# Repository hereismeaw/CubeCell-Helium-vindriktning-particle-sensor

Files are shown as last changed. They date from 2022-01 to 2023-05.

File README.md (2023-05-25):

# Helium LoRaWAN connectivity for the Ikea VINDRIKTNING

This repository contains an Heltec CubeCell firmware, which adds Helium LoRaWAN connectivity to the Ikea VINDRIKTNING PM2.5 air quality sensor.
The modification doesn't interfere with normal operation of the IKEA device in any way.
The CubeCell just adds another data sink beside the colored LEDs.

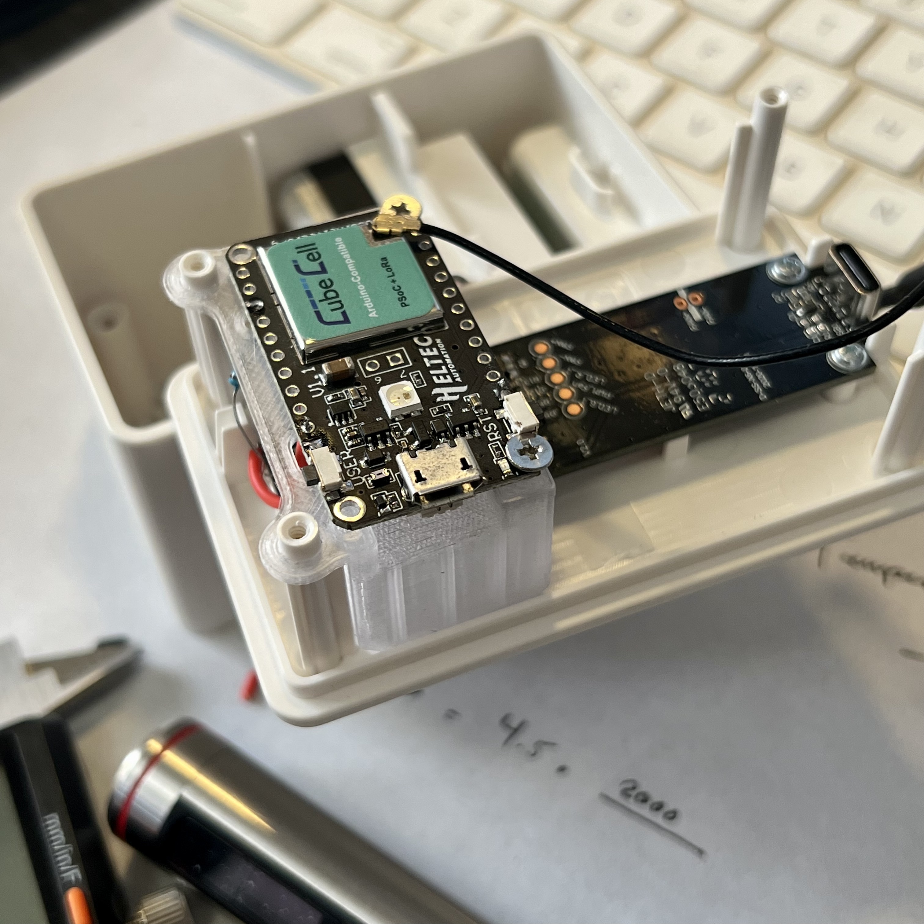
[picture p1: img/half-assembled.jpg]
half_assembled


The CubeCell seems to be 5V-tolerant, but just in case you can wire in the data line with a voltage divider.
## Prerequisites
To extend your air quality sensor, you will need

- A LoRaWAN-enabled dev board, in this case the [Heltec CubeCell HTCC-AB01](https://heltec.org/project/htcc-ab01/) ([US Domestic](https://shop.parleylabs.com/collections/iot-developers-products/products/cubecell-dev-board-by-heltec-htcc-ab01))
- Some short dupont cables
- A soldering iron
- A long PH0 Screwdriver (e.g. Wera 118022)

Fortunately, there is a lot of unused space in the enclosure, which fits the HTCC-AB01 well.
Also, everything we need is accessible via easy to solder testpoints.
## Hardware
To install, just unscrew the four visible screws in the back of the enclosure.

There are also three screws holding the IKEA PCB in place. These aren't necessary to remove since you can solder in-place, however personally, I'd recommend taking the board out of there since it will be easier to solder without fear of accidentally melting some plastic.

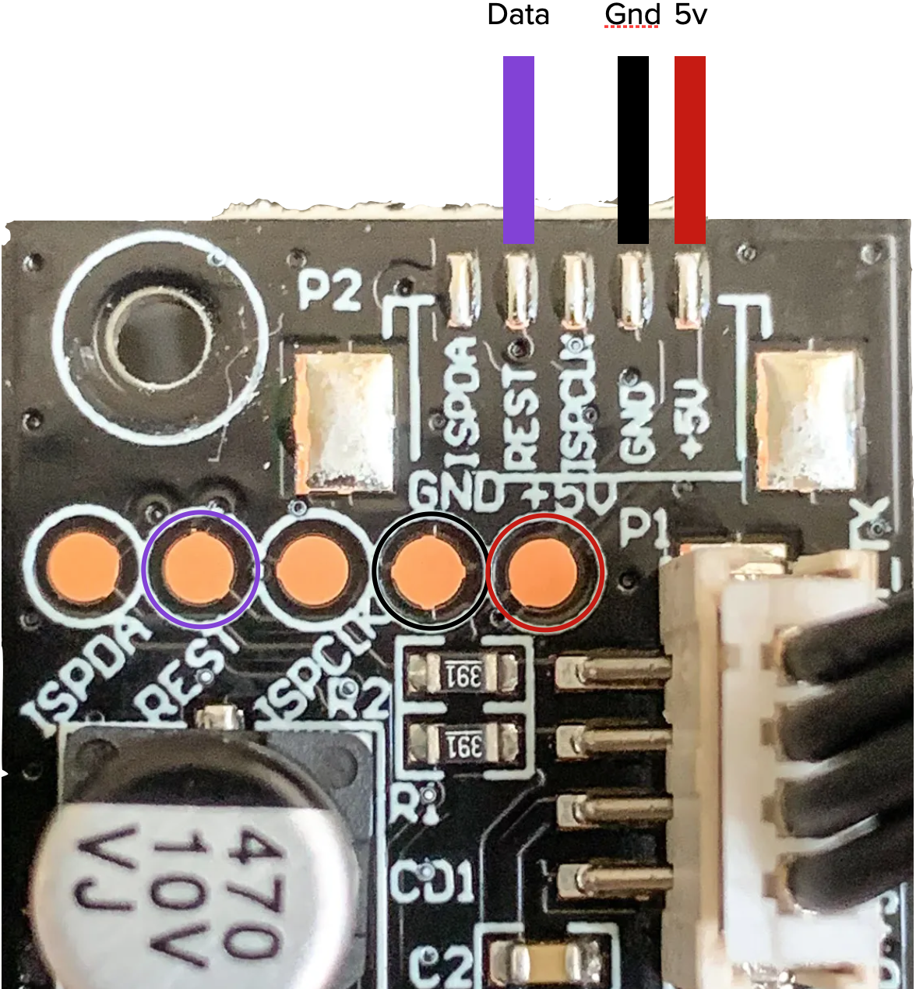
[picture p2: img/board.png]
board


As you can see in this image, you'll need to solder wires to GND, 5V and the Testpoint that is connected to TX of the Particle Sensor.

Then just connect these Wires to GND, VIN (5V) and Pin 2 on the CubeCell.
<table>
  <tr>
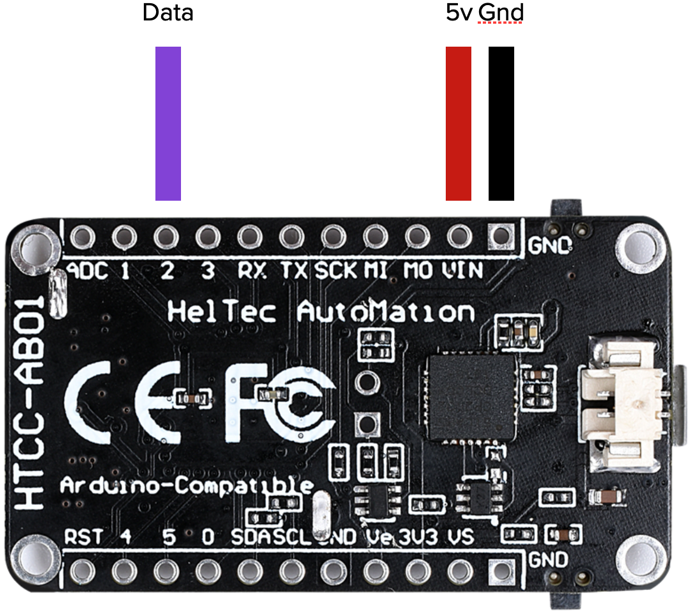
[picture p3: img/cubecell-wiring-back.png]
    <td valign="bottom"></td>
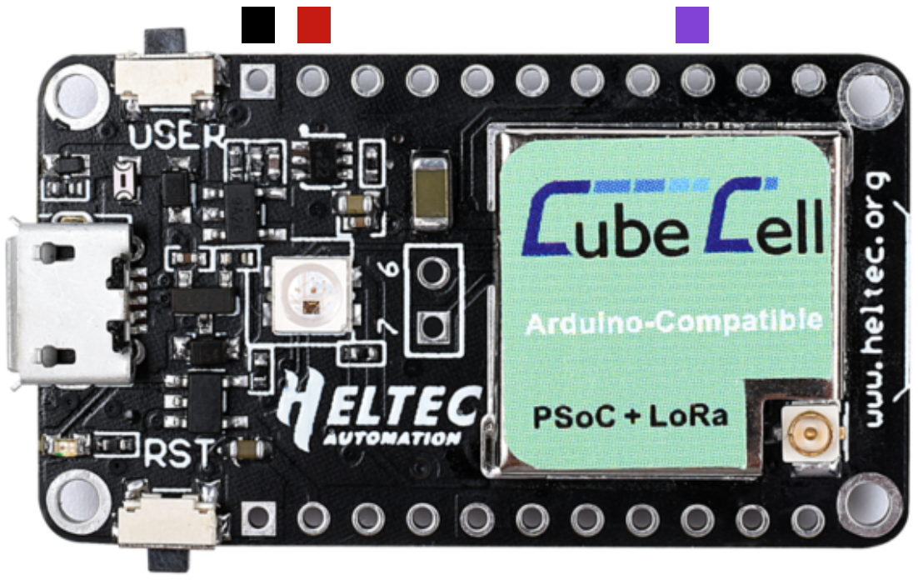
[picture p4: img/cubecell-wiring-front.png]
    <td valign="bottom"></td>
  </tr>
</table>

[Optional] If you choose to include a voltage divider, you can wire it in as follows:
voltage divider

Done.
## Software
The firmware can be built and flashed with [VS Code](https://code.visualstudio.com) using the PlatformIO plugin. PRs welcome for any Arduino IDE support/testing.

You can follow the guide below to set up the PlatformIO environment and CubeCell board:

https://docs.helium.com/use-the-network/devices/development/heltec/cubecell-dev-board/platformio/

LoRaWAN network keys will need to be added in the code. All keys are MSB.
After keys are added; just build, flash, and you're done.

## Downlinks
### Update Interval
By default, the sensor will update on a 1 minute interval. LoRaWAN update interval is configurable via LoRaWAN downlink. Set the interval in hours, minutes, or both. Values are submitted in two separate buckets, `[hours]` and `[minutes]`. Values up to 255 are supported in each bucket. Use a tool like https://v2.cryptii.com/decimal/base64 to convert the two values into base64 before submitting them as a downlink in Helium Console. e.g.
```
"00 15" converts to "AA8=", representing 0 hrs, 15 min
```
Values are added, so `01 15` is equivalent to `00 75`. Further, `02 00` = `00 120` etc.

## Misc
The VINDRIKTNING consists of a custom(?) Cubic PM1006-like Sensor + another uC that does all that LED stuff, which talk via UART. Therefore, to add LoRaWAN connectivity, we just need to also listen to the TX of the Sensor and decode those messages.
The transitions from Green to Yellow and Yellow to Red in the Ikea firmware are at around 30μg/m³ and 100μg/m³. There is a great analysis of the sensor's capabilities [here](https://www.airgradient.com/resources/ikea-vindriktning-accuracy/).
## References and sources
- [Source Repo](https://github.com/Hypfer/esp8266-vindriktning-particle-sensor)
- [Sensor analysis](https://www.airgradient.com/resources/ikea-vindriktning-accuracy/)
- [@haxfleisch](https://twitter.com/haxfleisch) for their teardown of the device.
- [Gabriel Valky](https://github.com/gabonator) for the incredibly useful [LA104 custom firmware + tools](https://github.com/gabonator/LA104)

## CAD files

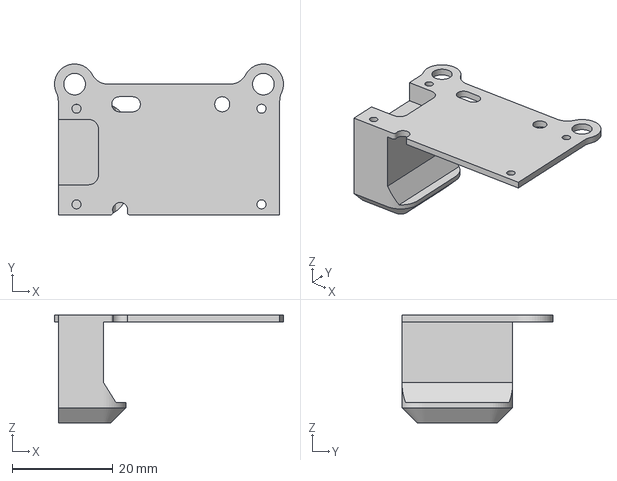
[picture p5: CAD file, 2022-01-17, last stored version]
3d_print/Vindriktning-Cubecell-Mount.3mf
45.5 x 30.0 x 21.4 mm

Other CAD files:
3d_print/Vindriktning-Cubecell-Mount.f3d
3d_print/Vindriktning-Cubecell-Mount.stl

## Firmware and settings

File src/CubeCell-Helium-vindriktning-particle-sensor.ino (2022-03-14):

#include "LoRaWan_APP.h"
#include "Arduino.h"
#include "SerialCom.h"
#include "types.h"

particleSensorState_t state;

/* OTAA para*/
/* All keys MSB */
uint8_t devEui[] = { 0x00, 0x00, 0x00, 0x00, 0x00, 0x00, 0x00, 0x00 };
uint8_t appEui[] = { 0x00, 0x00, 0x00, 0x00, 0x00, 0x00, 0x00, 0x00 };
uint8_t appKey[] = { 0x00, 0x00, 0x00, 0x00, 0x00, 0x00, 0x00, 0x00, 0x00, 0x00, 0x00, 0x00, 0x00, 0x00, 0x00, 0x00 };

/* ABP para*/
uint8_t nwkSKey[] = { 0x15, 0xb1, 0xd0, 0xef, 0xa4, 0x63, 0xdf, 0xbe, 0x3d, 0x11, 0x18, 0x1e, 0x1e, 0xc7, 0xda,0x85 };
uint8_t appSKey[] = { 0xd7, 0x2c, 0x78, 0x75, 0x8c, 0xdc, 0xca, 0xbf, 0x55, 0xee, 0x4a, 0x77, 0x8d, 0x16, 0xef,0x67 };
uint32_t devAddr =  ( uint32_t )0x007e6ae1;

/*LoraWan channelsmask, default channels 0-7*/ 
// uint16_t userChannelsMask[6]={ 0x00FF,0x0000,0x0000,0x0000,0x0000,0x0000 };
uint16_t userChannelsMask[6] = { 0xFF00,0x0000,0x0000,0x0000,0x0000,0x0000 }; //Helium Channel Mask

/*LoraWan region, select in arduino IDE tools*/
LoRaMacRegion_t loraWanRegion = ACTIVE_REGION;

/*LoraWan Class, Class A and Class C are supported*/
DeviceClass_t  loraWanClass = LORAWAN_CLASS;

/*the application data transmission duty cycle.  value in [ms].*/
uint32_t appTxDutyCycle = 1800000; //30 min default. Configurable using Downlink

/*OTAA or ABP*/
bool overTheAirActivation = LORAWAN_NETMODE;

/*ADR enable*/
bool loraWanAdr = LORAWAN_ADR;

/* set LORAWAN_Net_Reserve ON, the node could save the network info to flash, when node reset not need to join again */
bool keepNet = LORAWAN_NET_RESERVE;

/* Indicates if the node is sending confirmed or unconfirmed messages */
bool isTxConfirmed = LORAWAN_UPLINKMODE;

/* Application port */
uint8_t appPort = 2;
/*!
* Number of trials to transmit the frame, if the LoRaMAC layer did not
* receive an acknowledgment. The MAC performs a datarate adaptation,
* according to the LoRaWAN Specification V1.0.2, chapter 18.4, according
* to the following table:
*
* Transmission nb | Data Rate
* ----------------|-----------
* 1 (first)       | DR
* 2               | DR
* 3               | max(DR-1,0)
* 4               | max(DR-1,0)
* 5               | max(DR-2,0)
* 6               | max(DR-2,0)
* 7               | max(DR-3,0)
* 8               | max(DR-3,0)
*
* Note, that if NbTrials is set to 1 or 2, the MAC will not decrease
* the datarate, in case the LoRaMAC layer did not receive an acknowledgment
*/
uint8_t confirmedNbTrials = 4;

unsigned char *puc;
/* Prepares the payload of the frame */
static void prepareTxFrame( uint8_t port )
{
	/*appData size is LORAWAN_APP_DATA_MAX_SIZE which is defined in "commissioning.h".
	*appDataSize max value is LORAWAN_APP_DATA_MAX_SIZE.
	*if enabled AT, don't modify LORAWAN_APP_DATA_MAX_SIZE, it may cause system hanging or failure.
	*if disabled AT, LORAWAN_APP_DATA_MAX_SIZE can be modified, the max value is reference to lorawan region and SF.
	*for example, if use REGION_CN470, 
	*the max value for different DR can be found in MaxPayloadOfDatarateCN470 refer to DataratesCN470 and BandwidthsCN470 in "RegionCN470.h".
	*/
    appDataSize = 2;

    puc = (unsigned char *)(&state.avgPM25);
    appData[0] = puc[1];
    appData[1] = puc[0];
}

//downlink data handling function
void downLinkDataHandle(McpsIndication_t *mcpsIndication) {
    Serial.printf("+REV DATA:%s,RXSIZE %d,PORT %d\r\n",mcpsIndication->RxSlot?"RXWIN2":"RXWIN1",mcpsIndication->BufferSize,mcpsIndication->Port);
    
    switch (mcpsIndication->Port) {
    case 1:
        /* Set update interval on port 1 */
        Serial.println("Setting new update interval.");
        Serial.print("Hours: ");
        Serial.println(mcpsIndication->Buffer[0]);
        Serial.print("Minutes: ");
        Serial.println(mcpsIndication->Buffer[1]);
        
        // Multiply slot 1 by 1 hr, slot 2 by 1 minute.
        // Values (0-255) submitted in hex. 
        // Use a tool like https://v2.cryptii.com/decimal/base64. 
        // e.g. `0 15` -> `AA8=` Representing 15 minute interval.
        appTxDutyCycle = (3600000 * mcpsIndication->Buffer[0]) + (60000 * mcpsIndication->Buffer[1]);
        break;
    case 2:
        // todo: control LED on port 2
        // todo: party mode???
        break;
    default:
        break;
    }
}

void setup() {
	boardInitMcu();
	Serial.begin(115200);
	SerialCom::setup();
#if(AT_SUPPORT)
	enableAt();
#endif
	deviceState = DEVICE_STATE_INIT;
	LoRaWAN.ifskipjoin();
}

void loop() {
	SerialCom::handleUart(state);
  
	switch( deviceState ){
		case DEVICE_STATE_INIT:
		{
#if(LORAWAN_DEVEUI_AUTO)
			LoRaWAN.generateDeveuiByChipID();
#endif
#if(AT_SUPPORT)
			getDevParam();
#endif
			printDevParam();
			LoRaWAN.init(loraWanClass,loraWanRegion);
			deviceState = DEVICE_STATE_JOIN;
			break;
		}
		case DEVICE_STATE_JOIN:
		{
			LoRaWAN.join();
			break;
		}
		case DEVICE_STATE_SEND:
		{
			prepareTxFrame( appPort );
			LoRaWAN.send();
			deviceState = DEVICE_STATE_CYCLE;
			break;
		}
		case DEVICE_STATE_CYCLE:
		{
			// Schedule next packet transmission
			txDutyCycleTime = appTxDutyCycle + randr( 0, APP_TX_DUTYCYCLE_RND );
			LoRaWAN.cycle(txDutyCycleTime);
			deviceState = DEVICE_STATE_SLEEP;
			break;
		}
		case DEVICE_STATE_SLEEP:
		{
			LoRaWAN.sleep();
			break;
		}
		default:
		{
			deviceState = DEVICE_STATE_INIT;
			break;
		}
	}
}

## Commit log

2022-01-17 Adds bracket files
    [Vindriktning-Cubecell-Mount.3mf, Vindriktning-Cubecell-Mount.f3d]
2022-01-18 Adding STL
    [Vindriktning-Cubecell-Mount.stl]
